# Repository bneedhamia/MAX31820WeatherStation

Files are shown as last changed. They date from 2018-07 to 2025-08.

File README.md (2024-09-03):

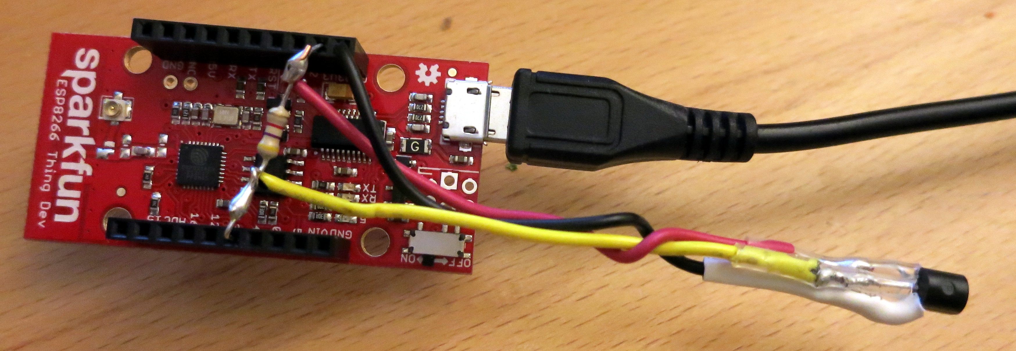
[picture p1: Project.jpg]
The Project so far

# MAX31820WeatherStation
An Arduino Sketch for a Sparkfun ESP8266 Thing Dev board, using a MAX31820 temperature sensor to sense and report the current ambient temperature to the Weather Underground via WiFi.

The state of the project: My weather station is installed on my garage wall, in the shade, and is sending the temperature to Weather Underground every 5 minutes. See Diary.odt for details.

The Arduino Sketch requires a Sparkfun ESP8266 Thing Dev board, a MAX31820 temperature sensor, a 4.7K Ohm pull-up resistor and a few wires. Details are in BillOfMaterials.ods. Total cost: about $28 USD.

I've posted a How-To in my BluePaperTech.com post [Build a Minimal Weather Underground Station](https://bluepapertech.com/electronics/build-a-minimal-weather-underground-station/).

## Files
* BillOfMaterials.ods = the parts list.
* box.stl = the 3D printing file for the box that holds the parts. Print in PLA, with no support, raft, or brim.
* boxLid.stl = the 3D printing file for the box's lid. Print in PLA, with no support, raft, or brim.
* Diary.odt = my journal/diary of the project, with design and assembly details.
* LICENSE = the project GPL2 license file.
* MAX31820WeatherStation.ino = the ESP8266 Arduino Sketch.
* MAX31820WeatherStation.FCStd = the FreeCAD design file for the box.
* MAX31820WeatherStation.fzz = the Fritzing (circuit wiring) diagram. See [Fritzing.org](http://fritzing.org)
* Project.jpg = a photo of the project so far.
* README.md = this file.

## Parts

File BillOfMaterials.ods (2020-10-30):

Bill Of Materials for MAX31820 Weather Underground station |  |  |  | All values are in US Dollars
Count | Name | Supplier | Part Number | Cost each | Total | Url | Notes
1 | SparkFun ESP8266 Thing - Dev Board | Sparkfun | WRL-13711 | $15.95 | $15.95 | https://www.sparkfun.com/products/13711
2 | Arduino Stackable Header - 10 Pin | Sparkfun | PRT-11376 | $0.50 | $1.00 | https://www.sparkfun.com/products/11376 | To plug wires into the ESP8266 Thing Dev board
1 | Wall Adapter Power Supply - 5.1V DC 2.5A (USB Micro-B) | Sparkfun | TOL-13831 | $7.95 | $7.95 | https://www.sparkfun.com/products/13831 | This supply powers the ESP8266
1 | One-Wire Ambient Temperature Sensor - MAX31820 | Sparkfun | SEN-14049 | $1.95 | $1.95 |  | Available for a little less at Digikey: https://www.digikey.com/product-detail/en/maxim-integrated/MAX31820MCR/MAX31820MCR-ND/4271348
10 | Resistor 4.7K OHM 1/4W 5% AXIAL | Digikey | 4.7KQBK-ND | $0.06 | $0.60 | https://www.digikey.com/products/en?keywords=4.7KQBK-ND | We need only 1, but they're useful enough to buy at least 10
1 | 3D Printed box with lid | -custom- |  |  |  | MAX31820WeatherStation.FCStd | Custom part. STL files and the Design file are in GitHub
 | TODO heat shrink tubing |  |  |  | $0.00
Total (Parts) |  |  |  |  | $27.45
Tools and Miscellaneous materials
1 | Heaterizer XL-3000 Heat Gun | Sparkfun | TOL-10326 | $13.95 | $13.95 |  | So much better and safer than trying to use matches or cigarette lighters to shrink the tubing.
1 | Hookup wire, solid, 22Awg, black | Sparkfun | PRT-08022 | $2.50 | $2.50 | https://www.sparkfun.com/products/8022 | Ground wires
1 | Hookup wire, solid, 22Awg, red | Sparkfun | PRT-08023 | $2.50 | $2.50 | https://www.sparkfun.com/products/8023 | Power wires
1 | Hookup wire, solid, 22Awg, yellow | Sparkfun | PRT-08024 | $2.50 | $2.50 | https://www.sparkfun.com/products/8024 | Arduino signal wires
Total (Wire and Tools) |  |  |  |  | $21.45

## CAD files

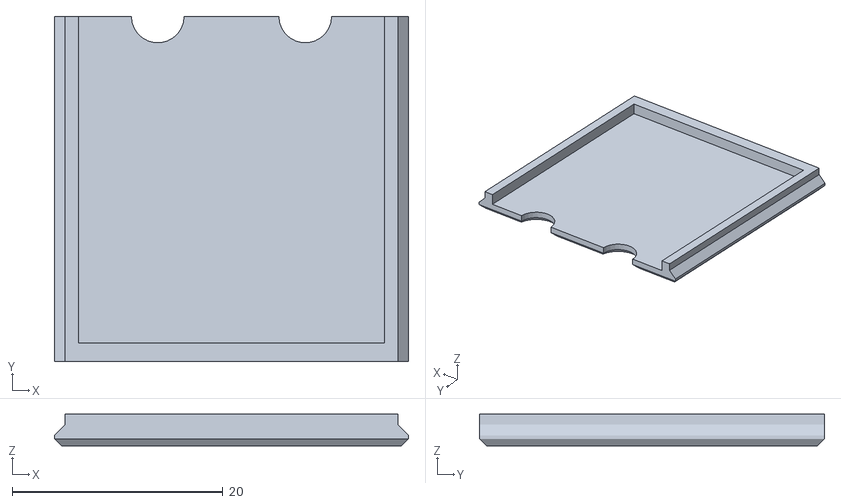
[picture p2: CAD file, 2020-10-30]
boxLid.stl
33.6 x 32.8 x 3.00

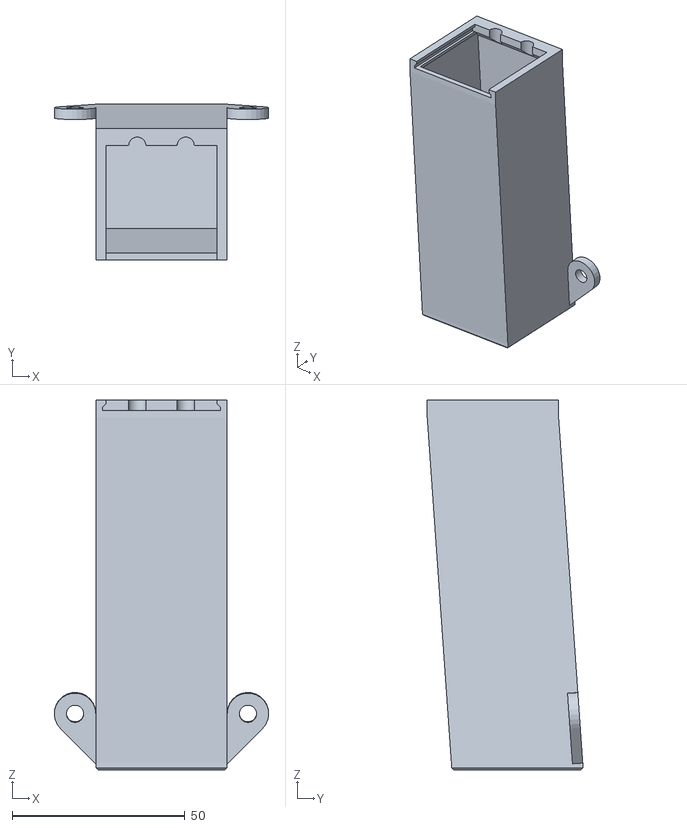
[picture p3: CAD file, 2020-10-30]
box.stl
62.0 x 45.0 x 107.0

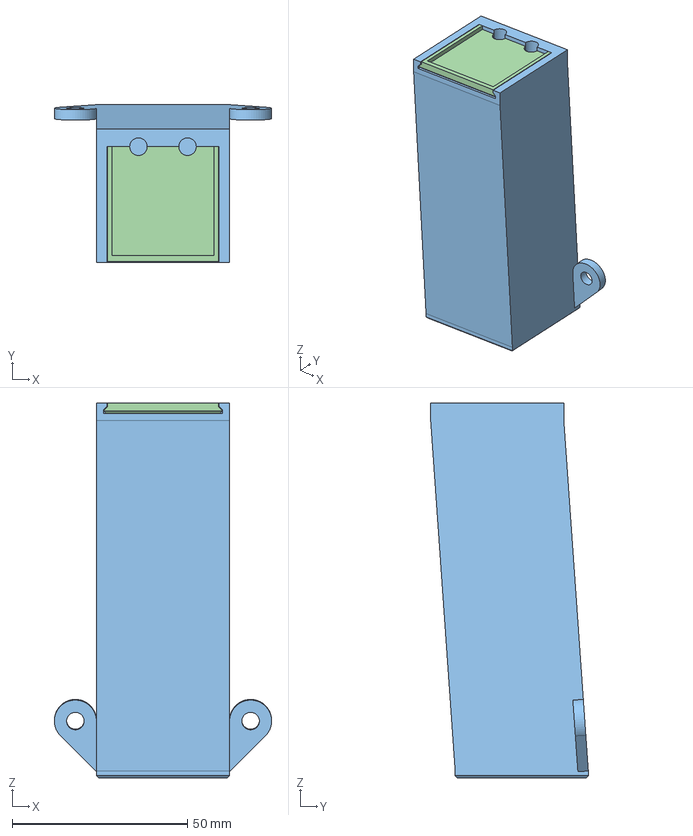
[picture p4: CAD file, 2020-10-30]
MAX31820WeatherStation.FCStd
62.0 x 45.0 x 107.0 mm
boxLid
RefinedBoxForPrinting
RefinedBoxLidForPrinting

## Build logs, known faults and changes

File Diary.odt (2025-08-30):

# Diary for the ESP8266 / MAX31820 Weather Underground Station

This project is a minimal, temperature-only weather station that reports to the Weather Underground, https://www.wunderground.com/ , via WiFi.

It uses a Sparkfun ESP8266 Thing Dev board as the Arduino, and one Max31820 Temperature Sensor to read the ambient temperature. The project is housed in a 3D printed box that has holes at the bottom for the USB power and the temperature sensor.

## 3D Printing and Assembly Instructions

1. I prefer PLA.
2. Print box.stl and boxLid.stl. Print without support, raft, or brim.
3. The lid may be a little tight the first few times you slide it in. It will loosen with wear.

## How to Register your Weather Station

1. Create a free account on Weather Underground, https://www.wunderground.com/
2. Log in to Weather Underground
3. Select, under My Profile, My Weather Stations
4. On the resulting screen, select the Register with WU tab
5. Follow the instructions to register your station, selecting "other" for Station Hardware.
6. Write down the resulting Station ID and Station Key. You will load these into the ESP8266 EEPROM so that the Arduino code doesn't have any private information in it. See instructions in the Arduino code (.ino) file for how to load the WiFi credentials and Station credentials into the ESP8266 EEPROM.
7. After a few minutes, power up your new weather station. It should upload the temperature every 10 minutes.

## Design Notes

- Weather Underground takes temperature in degrees Fahrenheit. The code converts from degrees Celsius (the MAX31820 native form) to degrees Fahrenheit for upload.
- My box will be put in a very damp environment (outside, under a balcony).
- The box holds an ESP8266 Thing Dev board and MAX31820 temperature sensor.
- It is powered by wall-powered USB, plugged into a nearby all-weather socket. My power supply is sheltered from the rain, so it should work fine. It will be interesting to see how it fares this winter. Update: it worked without problems.
- I created a slight slope to the top and bottom of the box by doing a Sweep operation. The slight slope should help keep water from pooling on the top of the box.
- The holes in the bottom lid of the box will pass the USB wire and the wires for the MAX31820.
- The temperature sensor is outside the box and below the ESP8266, to minimize the effect of the heat generated by the ESP8266.
- The ESP8266 board is 27mm wide. I added 2 mm clearance, so the box interior is 29 mm wide. The length from tip of pins to good clearance above the headers = about 29 mm, so I made the box square.
- From the tip of the ESP8266 board to the flexible part of the USB cable is 100 mm, so I made the box about 100 mm tall.
- The ESP8266 spec claims an operating temperature range of -40°~125° C, so we shouldn't have any trouble with low or high ambient temperatures here.

## Soldering the circuit

1. Solder the headers to the ESP8266.
2. Trim and bend the ends of the 4.7K Ohm resistor so it just fits with one end plugged into ESP8266 3.3V pin and the other into the data pin (labeled "4" on the ESP8266).
3. Cut 3 long (100 mm) pieces of hookup wire: Red for power, Yellow for data, and Black for ground. Solder them to the appropriate pins of the MAX31820. See the data sheet or my project photo for the pinout of the MAX31820. https://cdn.sparkfun.com/datasheets/Sensors/Temp/MAX31820.pdf
4. Cut 3 short pieces of heat shrink tubing. Slide one over each of the wires, to cover the soldered parts. Use a heat gun to shrink the tubing.
5. Solder the yellow data wire to the data (pin 4) side of the resistor.
6. Solder the red power wire to the power (3.3V) side of the resistor.
7. Cut the black wire to length and plug it into the GND pin on the ESP8266.

## Diary

August 30, 2025 – Extended the temperature wait time to fix an obscure 1 ms bug. Checked in the project using SSH.

August 29, 2025 – I think I have the SSH checkout/checkin figured out. Had to re-checkout the repository and fold in my changes because the old checkout wasn't with SSH.

February 12, 2025 – Put the new Weather Underground Certificate's fingerprint in the code.
Still haven't done the SSH work for Github.

September 3, 2024 – Updated the new Weather Underground Certificate's fingerprint in the code.
Unfortunately for me Github has changed the authentication method in the past few years and the instructions for using SSH with Github are tedious and full of options. I successfully changed the local repository's URL to SSH (see git remote -v), but the steps past that point are a mess.

October 23, 2021 – The station stopped working in July. Today I looked into it and found the Weather Underground site Certificate had been updated in July. Incorporated the new Certificate's fingerprint into the code and ran it; it uploaded just fine.

October 29 – the redesigned FreeCAD file prints and works great. I tightened the lid clearance so it won't fall out so easily.

October 27, 2020 – Autodesk changed the License terms for Fusion 360, so I'm switching back to FreeCAD, which is open source. I'm redesigning the weather station box from scratch to hopefully make a simpler design.

December 7 – Printed the Weather Station box. It works fine. Replaced the FreeCAD design file with a Fusion 360 design file; updated the .stl files.

December 6 - Finished the first draft of the 3D printed Weather Station box in Fusion 360. It's ready to print.

December 5 – Corrected the current time (millis()) to be unsigned long to match the return value from millis() and to correct some time rollover problems. It seems the code was correct; all I had to do was correct the declaration of nowMs.
Did some simple addition of an offset to the millis() result to test time rollover behavior of the time between Posts code. It succeeded.
Started working on the fix for the station not working if the WiFi Access Point is not available at ESP8266 powerup. Ran the HTTPSRequest Sketch (see notes below), testing the case of the AP not being up at startup (turning on after 5 minutes) – the ESP8266 library worked fine. Added a State to the state machine that's for Waiting For Access Point. Tried it out: it successfully handled powering up followed by the Access Point powering up a minute later.
Wrote a simple UrlEncoder and a unit test for it. The output is:

Output should be URL Encoded 0x01 through 0xff

%01%02%03%04%05%06%07%08%09%0A%0B%0C%0D%0E%0F%00%01%02%03%04%05%06%07%08%09%0A%0B%0C%0D%0E%0F%00%01%02%03%04%05%06%07%08%09%0A%0B%0C%0D%0E%0F...

So it looks like the upper digit isn't coming out correctly. It was a simple typo of >>8 instead of >>4. Fixed that and it ran fine.
Tested the normal running of the Sketch; the upload failed with "Unauthorized". So something's wrong with the urlencodedcat() use. Added a debug print of the Post content: the station ID and password look like they weren't null terminated: they contain piles of garbage characters. Read the function and found I'd forgotten to null terminate the output. Fixed that and the upload worked.
Started recreating the station 3D printed box in Fusion 360. The basic box and nail loops went together quickly. Took several tries at the slot for the case's bottom; I need to do one more try from scratch.

December 4, 2019 – Ran the weather station in my office. Changed the EEPROM to talk to the local SSID rather than the garage SSID. The sketch successfully connects to the local SSID, then says "Failed to connect to weatherstation.wunderground.com port 443". This happens before it even sends the SSL fingerprint. Perhaps the protocol has changed.
Found the URL of the protocol no longer works (404). Searched in vain for the Weather Underground Personal Weather Station protocol specification on the Weather Underground site.
Tried manually accessing the station update url of https://weatherstation.wunderground.com/weatherstation/updateweatherstation.php, and received a "bad request" response. That's good, that I didn't get a Not Found or other error.
Found a likely protocol description at The Weather Channel: https://feedback.weather.com/customer/en/portal/articles/2924682-pws-upload-protocol?b_id=17298, last updated June 2019. The protocol documented there seems unchanged.
Put the new update site in the code and tried it. Same error. Tried HTTP instead of HTTPS. Tried connecting to google.com via SSL. Same error, which suggests the problem is not the protocol, but is something to do with the network stack on the ESP8266.
Started reading the ESP8266 WiFi documentation, and found the WiFiClientSecure constructor is active, and should (likely) be constructed during setup() rather than at global variable initialization time before setup() is called. Changed doHttpsPost() to construct client each time it's called. No change.
Decided I need to back up and get a simple web client working again. Successfully ran the ESP8266 BasicHTTPSClient.ino example, so that shows the board works, but that code is very different than what this Sketch uses.
Once I corrected the fingerprint, I successfully ran https://github.com/esp8266/Arduino/blob/master/libraries/ESP8266WiFi/examples/HTTPSRequest/HTTPSRequest.ino, which uses the same API as this Sketch does/did. The big difference is that the working code uses client.fingerprint() to set the SSL fingerprint to use, while the non-working code uses the – very suspect – client.verify(fingerprint, host).
Updated the fingerprint setting code, corrected the fingerprint for the upload site – which was not the same as the one for the main wunderground.com site – and the Sketch successfully uploaded the temperature!
Implemented corrections to a few easy issues listed in this project's github repository.

December 1, 2019 – I took the station down sometime in the past year. I believe I did it because the station wasn't uploading to Weather Underground at all.
Read through the code, creating a GitHub Issue for each change that should be made.
Found that the SSL fingerprint for Weather Underground's site certificate is out of date; the corresponding SSL Certificate expired in September.

July 27 – Changed the upload interval from 10 minutes to 5 minutes, so Weather Underground won't mark a running station as down. Moved the weather station from the house balcony (which is typically 4 degrees Fahrenheit higher than the ambient air) to a garage wall that's in the shade. Found I forgot to reprogram the EEPROM to have it connect to the garage wifi hotspot. I also bent the sensor so it's a little further from the wall. We'll see if these changes improve the accuracy of the readings.

July 16, 2018 – Used two nails to hang the station on the outside wall of our balcony, reasonably sheltered from the sun. It's uploading just fine, and reads about 2 degrees F higher than a free-standing thermometer on the balcony.

July 15, 2017 – Built the hardware. Did a couple false starts because I'd forgotten why I was going to use a MAX31820 rather than a DHT22: the DHT22 is a 5.5V part and the ESP8266 Thing Dev is a 3.3V part. Also had forgotten that the 1-wire bus needs an external pullup resistor, so I need to solder something up rather than just using hookup wires with connectors on the ends.
Also found I seem to be out of MAX31280 parts. Need to order more. Stole one from my well depth sensor project.
I soldered the whole thing together: soldering the wires for power and data to either side of the 4.7K ohm pull-up resistor, soldered and heat-shrink-tubing covered the power, data, and ground hookup wires to the 3 pins of the temperature sensor.
Wrote the software: I modified my unfinished Well depth sensing Arduino Sketch, because that sketch reads from a set of MAX31820's and posts the results. Managed to run the sketch to print the 1-wire address of the temperature sensor I've soldered together (so Good News: I didn't break or overheat the sensor when soldering it.
Started putting together all the files for a github repository.

February 2 – Added lobes for nails/screws to fasten the box to the wall. Thought about, and initially discarded, the idea of sloping the top (bottom) so rain doesn't collect on the top of the box. If I redo the box, I'll do that plus I'll invert it so the model is right-side up for use (upside-down for printing).

Tried to print, but found after 45 minutes that it seems Cura decided that the box needed to be filled completely. Examining the bad file, I found doing a "Check Geometry" on the box model showed a fusion problem, and doing a Layers view in Cura also showed the problem of filling the entire box – so if I'd checked Geometry or looked at layers (always check layers view), I would have seen the problem without wasting plastic.

Redesigned the box from scratch, making it an angled thing to keep the rain out, and designing it upright, with the understanding that I print it all upside-down.

December 24 – With the snow and iffy weather, an outdoor thermometer sounds useful again.

Increased the horizontal clearance of the door from 0.5mm total (0.25mm each side) to 0.75 mm total (0.375mm per side).

December 2, 2017 – Considering different ways to enclose the ESP8266, to keep it dry enough. Thinking about a 3D printed, tube-like box with a slide-snap bottom. Did a quick sketch and printed a short version of the box as a clearance test. Found a couple things to fix.

Did a second iteration. Started a full-sized print. Still need to add something to fasten it to the side of the house.

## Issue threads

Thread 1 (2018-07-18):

10 minute updates make Weather Underground report that the station is down

bneedhamia, 2018-07-18:
The current Sketch reports the temperature every 10 minutes. I once saw Weather Underground report that my Personal Weather Station wasn't reporting, and that the latest report was from just a few minutes ago.

I've searched, but haven't (yet) found any Weather Underground specification of how infrequently a station can report and still be considered up.

I have found reports elsewhere that make me think that reducing the time between reports to 5 or 4 minutes would be a good idea. Some commercial weather stations seem to report once per minute or more frequently, to report the changing wind direction or swiftly-changing temperature.

Doing an informal survey of Weather Underground Personal Weather Station update times (as shown in WU's tabular weather data for a station) shows most of them are reporting about once per 5 minutes.

I recommend changing the reporting interval from 10 minutes to 5 minutes.

bneedhamia, 2018-07-27:
Weather Underground data table shows this station is now reporting every 5 minutes.

Closed 2018-07-27.

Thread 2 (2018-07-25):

Won't reconnect if wifi is down on powerup

bneedhamia, 2018-07-25:
The Sketch attempts to connect to WiFi only in Setup(), and goes to an error state if it can't connect. If the WiFi hotspot is down when the station is powered up, the station won't report until the station power is manually reset.

In short, the station won't recover properly from a power outage, because when power is restored, the WiFi isn't up yet when the station powers up.

The fix: expand the state machine to include WiFi connection-related states.

bneedhamia, 2019-12-05:
I tested the ESP8266 HTTPSRequest Sketch (https://github.com/esp8266/Arduino/blob/master/libraries/ESP8266WiFi/examples/HTTPSRequest/HTTPSRequest.ino), which simply waits forever for the WiFi Access Point to connect. Found I can start that Sketch with the AP off, turn the AP on 10 minutes later, and the Sketch will connect to it and run.
So I want to add a state to the loop() State Machine that indicates the Sketch is waiting for the ESP8266 to connect to the Access Point. I'll also make the EEPROM timeout parameter unused, but will leave it in in case a later version needs it.

bneedhamia, 2019-12-05:
Successfully tested the waiting for the WiFi AP to power up, and the new EEPROM layout that doesn't have a WiFi AP timeout.

bneedhamia, 2020-01-07:
We had a brief power outage, where the internet came up several minutes after the power came on. The station successfully resumed updating when the net came back.

Closed 2019-12-05.

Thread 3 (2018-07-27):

Serial Output of temperature should show units (C)

bneedhamia, 2018-07-27:
A very minor nit: the Serial printout of temperature doesn't say that it's C rather than F. It's pretty easy to guess that on a hot day a temperature of 28 isn't in Fahrenheit, but it's nice to be sure.

Add a "C" after the serial printout of the temperature in C.

bneedhamia, 2019-12-05:
Verified that it prints "C" after the debug temperature output.

Closed 2019-12-05.

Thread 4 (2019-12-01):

Won't upload to Weather Underground?

bneedhamia, 2019-12-01:
I seem to recall I took the station down because it no longer uploaded to Weather Underground.

TO DO: Check whether or not it uploads, and if not, find what the problem is.

bneedhamia, 2019-12-01:
One cause: the SSL Certificate I used a few years ago expired in September of 2019. So I need to re-read the Weather Underground's SSL Certificate, generate its fingerprint (as described in the .ino file) and manually update sslFingerprint[].

bneedhamia, 2019-12-05:
The problem seems to be the use of the ESP8266 WiFi stack rather than any change in the protocol. Even trying to connect to google.com on port 443 fails.

bneedhamia, 2019-12-05:
I watched it successfully upload my office temperature to Weather Underground 4 times.

Closed 2019-12-05.

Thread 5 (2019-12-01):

Change httpAgent to MAX31820WeatherStation

bneedhamia, 2019-12-01:
The current httpAgent name of the station, ESP8266HttpsClient, is too generic. Change httpAgent to the name of this repository, so that if there's a problem and someone searches the web for MAX31820WeatherStation, they'll find this repository.

bneedhamia, 2019-12-05:
Seems to work with the new HTTPS client name.

Closed 2019-12-05.

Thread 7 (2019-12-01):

In loop(), change nowMs to unsigned long, and correct related code

bneedhamia, 2019-12-01:
In loop() the current time, nowMs, is currently a signed long, but millis() returns an unsigned long. This means that nowMs will change from a positive to a negative number as the program runs. I believe this currently doesn't cause an error, but it's misleading and could easily cause future code changes to be incorrect.

bneedhamia, 2019-12-05:
Tested the time rollover for Post timing; it seemed to work.

Closed 2019-12-05.

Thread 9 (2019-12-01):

Add Fusion 360 design file for the case

bneedhamia, 2019-12-01:
I was using FreeCAD when I designed the case for the station. Since then I've switched to Fusion 360, which seems far more popular than FreeCAD in the 3D printing community.

Create a new case design in Fusion 360 and create new .STL files. Remove the old case design.

bneedhamia, 2019-12-08:
Tried out the new, Fusion 360 based, box for the weather station. It's almost identical to the FreeCAD version.

Closed 2019-12-08.

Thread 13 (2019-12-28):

Add 1 millisecond to temperature reading delay

bneedhamia, 2019-12-28:
I believe that some of the time the temperature is read before it's ready.

The MAX31820 Datasheet, https://cdn.sparkfun.com/datasheets/Sensors/Temp/MAX31820.pdf, specifies the maximum temperature conversion time for a 12-bit reading is 750ms. The Dallas Temperature library, https://github.com/milesburton/Arduino-Temperature-Control-Library/blob/master/DallasTemperature.cpp, returns, for the time required for a 12-bit conversion, 750ms. Meanwhile this Sketch code tests whether it's time to read the converted temperature via an if statement that says whether it's not yet time: (long) (nowMs - stateBegunMs) < wireDevices.millisToWaitForConversion(MAX31820_RESOLUTION_BITS)

The bug is that the Sketch doesn't allow for millis() rounding/truncation of the current time to milliseconds. For example, two subsequent calls to millis() could return results that differ by 1ms, even though the calls happened much less than 1ms apart. So any test of time that doesn't allow for this effect could say that things are ready as much as 1ms earlier than they really are.

Solution:  change the if statement in STATE_WAITING_FOR_TEMPERATURES to wait for the conversion time plus 1ms, to be safe.

bneedhamia, 2025-08-30:
Added the 1ms delay.

Closed 2025-08-30.

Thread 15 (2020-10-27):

Remove dependencies on the proprietary CAD program, Fusion 360

bneedhamia, 2020-10-27:
Fusion 360 is a proprietary application. Meanwhile, FreeCAD is FOSS (Free and Open Source Software).

Replace the 3D printing design file and output files with FreeCAD counterparts.

bneedhamia, 2020-10-30:
Replaced the Fusion 360 file with a new FreeCAD file.

Closed 2020-10-30.

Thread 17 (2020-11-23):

Upload is failing again - likely the Wunderground site certificate fingerprint needs to be updated.

bneedhamia, 2020-11-23:
My station stopped uploading months ago. I suspect the site certificate has been updated.

bneedhamia, 2020-11-23:
Recompiling in my office with new WiFi credentials and the same old code seems to work fine. Now I suspect the problem was with a WiFi hotspot that needed to be reset. Double-checked the site certificate fingerprint hasn't changed.

Closed 2020-11-23.

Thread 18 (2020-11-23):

Wunderground test URL in the comments is incorrect

bneedhamia, 2020-11-23:
"Browse to an https: page on the desired server.
       E.g., https://weatherstation.winderground.com" has a typo; that should be wunderground instead of winderground.
This typo led me to believe that the site or protocol had changed, because the browser reported the name wasn't found.

bneedhamia, 2020-11-23:
Corrected the typo.

Closed 2020-11-23.

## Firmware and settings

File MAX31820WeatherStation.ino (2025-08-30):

/*
   Arduino Sketch for a Sparkfun ESP8266 Thing Dev board
   to read the ambient temperature from a MAX31820 chip
   and send that temperature to Weather Underground.

   NOTE: You will need to update sensorAddress{}
   and likely update sslFingerprint[]. See the comments by those variables.
   You will also need to program the EEPROM. See "The EEPROM layout" below.

   Copyright (c) 2018, 2019 Bradford Needham
   { @bneedhamia , https://www.needhamia.com }

   Licensed under GPL V2
   a copy of which should have been supplied with this file.
*/
//345678901234567890123456789312345678941234567895123456789612345678971234567898

/*
   Flags to change the program behavior:
   
   PRINT_1_WIRE_ADDRESS = uncomment this line to only
     print the temperature sensor's 1-wire address,
     so you can copy it into the sensorAddress[] initializer.
     Comment this line out for normal Sketch behavior.

   TEST_URL_ENCODING = uncomment this line to only
     test the urlencodedcat() function.
     Used only during development of urlencodedcat().
     Comment this line out for normal Sketch behavior.
*/
//#define PRINT_1_WIRE_ADDRESS true
//#define TEST_URL_ENCODING true

/*
    NOTE: because the ESP8266 WiFi operates in the background,
     setup() and loop() must not take a long time.
     In particular, never call any delay() greater than
     a few hundred milliseconds.
 */
#include <ESP8266WiFi.h> // Defines WiFi, the WiFi controller object
#include <WiFiClientSecure.h>
#include <EEPROM.h>   // NOTE: ESP8266 EEPROM library differs from Arduino's.
#include <OneWire.h>  // https://github.com/PaulStoffregen/OneWire
#include <DallasTemperature.h> // https://github.com/milesburton/Arduino-Temperature-Control-Library

/*
   Web Site specific constants.
     host = the hostname of the server to connect to.
     port = the HTTPS port to connect to (443 is the default).
     sslFingerprint = the SHA1 fingerprint of the SSL Certificate
       of the web site we will be connecting to.
     httpProtocol = the protocol to use. Some sites prefer HTTP/1.1.
       This Sketch uses HTTP/1.0 to avoid getting a response that is
       Transfer-encoding: chunked
       which is hard to parse.
     url = the url, less https:// and the server name.
     httpAgent = a string to identify our client software.
       This Sketch uses the name of the Github Repository of this project.
       Replace this with whatever you like (no spaces).

     To Find the Fingerprint of a site:
     - Browse to an https: page on the desired server.
       E.g., https://weatherstation.wunderground.com
       (you may get a 404 error; that's ok).
     - Copy the certificate from that page. There are instructions
       on how to do this in various browsers. Search for
       "read the certificate from a website in Chrome" (without quotes)
       or whatever web client you prefer.
     - Save the certificate in Base-64 encoded X.509
     - In git bash (or in a linux terminal window), type
       openssl x509 -noout -fingerprint -sha1 -inform pem -in certificate-file.cer
       Where "certificate-file.cer" is the filename of the certificate you saved.
     - in the response, copy the colon-separated set of numbers.
     - paste them in the sslFingerprint initializer below.
     - replace each ":" character in sslFingerprint with a space.
     Note: when the site's certificate expires and is updated, you will need to
     update the code here with the new SSL certificate signature.

     The Weather Underground Personal Weather Station upload protocol
     is specified at https://support.weather.com/s/article/PWS-Upload-Protocol
*/
const char *host = "weatherstation.wunderground.com";
const int port = 443;
const char *sslFingerprint
  = "F1 C6 8A 62 8C 8B 1D 87 3A 29 10 B8 09 3F C1 96 79 A7 2E 35";
  // Certificate expires 12 Mar 2026, but it may be replaced earlier.
const char *httpProtocol = "HTTP/1.0";
const char *url = "/weatherstation/updateweatherstation.php";
const char *httpAgent = "MAX31820WeatherStation";

/*
   Hardware information:

   PIN_LED_L = LOW to light the on-board LED.
     The _L suffix indicates that the pin is Active-Low.
     Active-Low because that's how the ESP8266 Thing Dev board
     on-board LED is wired.
     When the LED is steady-on, we're waiting to connect to the WiFi.
     When the LED is blinking, we've encountered a non-recoverable error.
     When the LED is off, things are working correctly.
     
   PIN_ONE_WIRE = the 1-Wire bus data line for the temperature sensor.
   
   Note about the ESP8266 Thing Dev board I/O pins: several pins are unsuitable
   to be a 1-wire bus:
     0 is connected to an on-board 10K ohm pull-up resistor.
     2 is connected to an on-board 10K ohm pull-up resistor.
     5 is connected to an on-board LED and 220 ohm resistor to Vcc.
     15 is connected to an on-board 10K pull-down resistor.
     16 is not (currently) supported by the OneWire library, because
       that pin requires special treatment in the low-level I/O code.
*/
const int PIN_LED_L = 5;
const int PIN_ONE_WIRE = 4;

/*
   Time (milliseconds) per attempt to read and report the temperatures.
   Set this to about 5 minutes (1000L * 60L * 5L) for normal operation,
   so you don't overwhelm the server.
*/
const long MS_PER_TEMPERATURE_REQUEST = 1000L * 60L * 5L;

/*
   The resolution (number of bits) to set the temperature sensor to.
   12 is the maximum; 9 is the minimum.
   Higher resolution takes longer (see the Max31820 datasheet for details)
   but is more precise.
*/
const uint8_t MAX31820_RESOLUTION_BITS = 12;

/*
   The EEPROM layout, starting at START_ADDRESS, is:
   String[EEPROM_WIFI_SSID_INDEX] = WiFi SSID. A null-terminated string
   String[EEPROM_WIFI_PASS_INDEX] = WiFi Password. A null-terminated string
   String[EEPROM_STATION_ID_INDEX] =
     the HTTPS POST Weather Underground station ID parameter to send.
   String[EEPROM_STATION_KEY_INDEX] =
     the HTTPS POST Weather Underground station key parameter to send.
   EEPROM_END_MARK

   To create a Station ID and Key for your particular weather station,
   visit https://www.wunderground.com/member/devices/new

   To write these values, use the Sketch write_eeprom_strings.
   See https://github.com/bneedhamia/write_eeprom_strings
   Modify that Sketch, replacing the initialization of STRING_NAME[] with
   the following lines:

  const char *STRING_NAME[] = {
  "SSID",
  "Password",
  "stationId",
  "stationKey",
  0
  };

*/
const int START_ADDRESS = 0;      // The first EEPROM address to read from.
const byte EEPROM_END_MARK = 255; // marks the end of the data we wrote to EEPROM
const int EEPROM_MAX_STRING_LENGTH = 120; // max string length in EEPROM
const int EEPROM_WIFI_SSID_INDEX = 0;
const int EEPROM_WIFI_PASS_INDEX = 1;
const int EEPROM_STATION_ID_INDEX = 2;
const int EEPROM_STATION_KEY_INDEX = 3;

/*
   The states of the state machine that loop() runs.

   state = the current state of the machine. A STATE_* value.
   stateBegunMs = if needed, the time (millis()) we entered this state.

   STATE_ERROR = an unrecoverable error has occurred. We stop.
   STATE_WAITING_FOR_WIFI = we're waiting for the WiFi to connect
     with the Access Point.
   STATE_WAITING_FOR_TEMPERATURES = we've issued a command to the sensors
     to read the temperature, and are waiting for the time to read
     their responses.
     For example, a 12-bit temperature read requires 750ms.
     stateBegunMs = time (millis()) we entered this state.
   STATE_WAITING_FOR_NEXT_READ = we're waiting to request temperature again.
*/

const uint8_t STATE_ERROR = 0;
const uint8_t STATE_WAITING_FOR_WIFI = 1;
const uint8_t STATE_WAITING_FOR_TEMPERATURES = 2;
const uint8_t STATE_WAITING_FOR_NEXT_READ = 3;
uint8_t state;
unsigned long stateBegunMs = 0L;

/*
   wire = The 1-Wire (thermometer) interface manager.
   wireDevices = the manager for the1Wire devices (thermometers).
 */
OneWire wire(PIN_ONE_WIRE);
DallasTemperature wireDevices(&wire);

/*
   WiFi access point parameters, read from EEPROM.

   wifiSsid = SSID of the local WiFi Access Point to connect to.
   wifiPassword = Password of the Access Point.
*/
char *wifiSsid;
char *wifiPassword;

/*
   HTTPS POST private parameters, read from EEPROM.
   stationId = the POST 'ID' parameter.
   stationKey = the POST 'PASSWORD' parameter.
*/
char *stationId;
char *stationKey;

/*
   sensorAddress = the 1-wire address of the temperature sensor on the 1-wire bus.
   Update this array for your unique temperature sensor.

   Create this initializer by:
   1) Wiring up the temperature sensor to the ESP8266, as described in Diary.odt
   2) Uncommenting PRINT_1_WIRE_ADDRESS (above)
   3) Running the Sketch, and copying and pasting the output here.
   4) Commenting out PRINT_1_WIRE_ADDRESS (above)
   5) Running the Sketch as normal.
*/
DeviceAddress sensorAddress = {0x28, 0xAB, 0xA8, 0xA8, 0x7, 0x0, 0x0, 0x78};

/*
   The result of measurement:

   stationTemperatureC = the temperature (degrees Celsius) read from the sensor,
    or <= DEVICE_DISCONNECTED_C if the sensor failed.
*/
float stationTemperatureC;

// Called once automatically on ESP8266 Reset.
void setup() {
  Serial.begin(9600);
  delay(100); // give the Serial port time to power up.
  Serial.println(F("Reset."));

#if defined(TEST_URL_ENCODING)
  testUrlencodedcat();
  state = STATE_ERROR;
  return;
#endif // defined(TEST_URL_ENCODING)

  // Set up our pins.

  pinMode(PIN_LED_L, OUTPUT);
  digitalWrite(PIN_LED_L, HIGH); // ESP8266 Thing Dev LED is Active Low
  // PIN_ONE_WIRE is managed by the OneWire library.

  wireDevices.begin();  // searches the 1-wire bus for devices.

#if defined(PRINT_1_WIRE_ADDRESS)
  // Report the device addresses, in no particular order, and quit.
  print1WireAddresses();

  state = STATE_ERROR;
  return;
#endif

  // Read the wifi parameters from EEPROM, if they're there.
  wifiSsid = readEEPROMString(START_ADDRESS, EEPROM_WIFI_SSID_INDEX);
  wifiPassword = readEEPROMString(START_ADDRESS, EEPROM_WIFI_PASS_INDEX);
  if (wifiSsid == 0 || wifiPassword == 0) {
    Serial.println(F("EEPROM not initialized."));

    state = STATE_ERROR;
    return;
  }

  // Read our Weather Underground station credentials from EEPROM
  stationId = readEEPROMString(START_ADDRESS, EEPROM_STATION_ID_INDEX);
  stationKey = readEEPROMString(START_ADDRESS, EEPROM_STATION_KEY_INDEX);
  if (stationId == 0 || stationKey == 0) {
    Serial.println(F("EEPROM not initialized."));

    state = STATE_ERROR;
    return;
  }

  /*
     Set up the temperature sensor:
     Set the digital temperature resolution.
     Set the library to have requestTemperatures() return immediately
       rather than waiting the (too long for our WiFi) conversion time.
  */
  wireDevices.setResolution(MAX31820_RESOLUTION_BITS);
  wireDevices.setWaitForConversion(false);

  // Finally, do the one-time WiFi setup and request connection
  WiFi.mode(WIFI_STA);    // Station (Client), not soft AP or dual mode.
  WiFi.setAutoConnect(false); // don't connect until we call .begin()
  WiFi.setAutoReconnect(true); // if the connection drops, reconnect.

  Serial.print(F("Connecting to "));
  Serial.println(wifiSsid);
  WiFi.begin(wifiSsid, wifiPassword);

  state = STATE_WAITING_FOR_WIFI;
  stateBegunMs = millis();
}

// Called repeatedly, automatically.
void loop() {
  unsigned long nowMs; // The current time (millis())
  int wifiStatus;  // connection state of the WiFi.

  nowMs = millis();

  switch (state) {
    case STATE_ERROR:
      // Blink the led.
      if (nowMs % 1000 < 500) { // will be slightly long at millis() rollover.
        digitalWrite(PIN_LED_L, LOW);
      } else {
        digitalWrite(PIN_LED_L, HIGH);
      }
      break;

    case STATE_WAITING_FOR_WIFI:
      // Waiting for either WiFi connection or connection failure.
      
      wifiStatus = WiFi.status();
      if (wifiStatus == WL_CONNECT_FAILED) {
        // bad password. Fail.
        Serial.print(F("Password incorrect for "));
        Serial.println(wifiSsid);
        state = STATE_ERROR;
        stateBegunMs = millis();
        
      } else if (wifiStatus == WL_NO_SSID_AVAIL) {
        // Show we're waiting.
        digitalWrite(PIN_LED_L, LOW);

        // Continue to wait for the WiFi AP to become available.
        // This state is our house-power-fail recovery state.
        
      } else if (wifiStatus == WL_CONNECTED) {
        // We've connected to WiFi. Start reading temperatures.
        Serial.print(F("Connected, IP address: "));
        Serial.println(WiFi.localIP());

        // Indicate we're working fine.
        digitalWrite(PIN_LED_L, HIGH);

        // Ask the sensor to read its temperature.
        wireDevices.requestTemperatures();
        state = STATE_WAITING_FOR_TEMPERATURES;
        stateBegunMs = millis();
      }
      break;

    case STATE_WAITING_FOR_TEMPERATURES:
      if ((long) (nowMs - stateBegunMs)
          < wireDevices.millisToWaitForConversion(MAX31820_RESOLUTION_BITS) + 1) {
        return; // wait more.
      }

      // The temperature is ready. Read and print it.
      stationTemperatureC = wireDevices.getTempC(sensorAddress);

      if (stationTemperatureC <= DEVICE_DISCONNECTED_C) {
        Serial.print("NC");
      } else {
        Serial.print(stationTemperatureC, 2);
        Serial.print(" C");
      }
      Serial.println();

      // Report our data to the web server.
      if (doHttpsPost()) {
        digitalWrite(PIN_LED_L, HIGH); // success: turn off the LED.
      } else {
        digitalWrite(PIN_LED_L, LOW); // recoverable failure: turn on the LED.
      }

      // Wait until it's time to request the temperature again.
      state = STATE_WAITING_FOR_NEXT_READ;
      stateBegunMs = millis();

      break;

    case STATE_WAITING_FOR_NEXT_READ:
      if ((long) (nowMs - stateBegunMs) < MS_PER_TEMPERATURE_REQUEST) {
        return; // wait more.
      }

      // Ask the sensor to read its temperature.
      wireDevices.requestTemperatures();
      state = STATE_WAITING_FOR_TEMPERATURES;
      stateBegunMs = millis();
      break;

    default:
      Serial.print("unknown state: ");
      Serial.println(state);
      state = STATE_ERROR;
      break;
  }
}

/*
    Uploads the temperature - that's all our weather station knows.
    Uses:
      stationId, stationKey
      stationTemperatureC
      and the server information (host, post, etc.)

    Returns true if successful, false otherwise.
*/
boolean doHttpsPost() {
  char content[1024];  // Buffer for the content of the POST request.
  char *pContent;  // a pointer into content[]
  char ch;

  // client = manager of the HTTPS connection to the web site.
  WiFiClientSecure client;


  /*
     Build the content of the POST. That is, the parameters.
     UrlEncode the fields that can contain arbitrary text. 
   */

  strcpy(content, "");

  strcat(content, "ID=");
  urlencodedcat(content, stationId);

  strcat(content, "&");
  strcat(content, "PASSWORD=");
  urlencodedcat(content, stationKey);
  
  strcat(content, "&");
  strcat(content, "action=updateraw"); // says "I'm posting the weather"

  strcat(content, "&");
  strcat(content, "dateutc=now"); // says when the data was collected
  
  if (stationTemperatureC > DEVICE_DISCONNECTED_C) {
    // Convert the temperature from Celsius to Fahrenheit
    float temperatureF = stationTemperatureC * (9.0 / 5.0) + 32.0;
    
    strcat(content, "&");
    strcat(content, "tempf=");
    floatcat(content, temperatureF);
  } // else ignore the disconnected sensor.

  // Perform the Post

  client.setFingerprint(sslFingerprint);
  if (!client.connect(host, port)) {
    Serial.print("Failed to connect to ");
    Serial.print(host);
    Serial.print(" port ");
    Serial.println(port);
    Serial.print(" using SSL fingerprint ");
    Serial.print(sslFingerprint);
    Serial.println();
    return false;
  }
  Serial.print("Connected to ");
  Serial.println(host);

  client.print("POST ");
  client.print(url);
  client.print(" ");
  client.println(httpProtocol);

  client.print("Host: ");
  client.println(host);

  client.print("User-Agent: ");
  client.println(httpAgent);

  client.println("Connection: close");

  client.println("Content-Type: application/x-www-form-urlencoded");

  client.print("Content-Length: ");
  client.println(strlen(content));

  client.println();  // blank line indicates the end of the HTTP headers.

  // send the content: the POST parameters.
  client.print(content);

  Serial.println("Reading response:");
  while (client.connected()) {
    if (client.available()) {
      ch = client.read();
      Serial.print(ch);
    }
    delay(1); // to yield the processor for a moment.
  }

  Serial.println();
  Serial.println("connection closed.");

  client.stop();

  return true;
}

/*
   Append (concatenate) the given floating-point number
   as a string to the given buffer.

   buffer = a space to concatenate into. It must contain a null-terminated
    set of characters.
   f = the floating point number to convert into a set of characters.

*/
void floatcat(char *buffer, float f) {
  char *p;
  long l;

  p = buffer + strlen(buffer);

  // Convert the sign.
  if (f < 0.0) {
    *p++ = '-';
    f = -f;
  }

  // Convert the integer part.
  l = (long) f;
  f -= (float) l;
  itoa(l, p, 10);
  p += strlen(p);

  // Convert the first 2 digits of the fraction.
  *p++ = '.';
  f *= 100.0;
  itoa((long) f, p, 10);
}

/*
   Append (concatenate) the given string to the given buffer,
   UrlEncoding the string as it is appended.

   buffer = a space to concatenate into. It must contain a null-terminated
    set of characters, and be large enough to store the result.
   str = points to the null-terminated string to UrlEncode and append.

*/
void urlencodedcat(char *buffer, char *str) {
  char *pBuf; // points to the next empty space in buffer[]
  char *pIn;  // points to a character in str[]
  char ch;  // the current input character to UrlEncode.
  char hexDigit[] = "0123456789ABCDEF";

  pBuf = buffer + strlen(buffer);
  
  for (pIn = str; *pIn; ++pIn) {
    ch = *pIn;
    if (isAlphaNumeric(ch)) {
      // Alphabetic and numeric characters are passed as-is.
      *pBuf++ = ch;
      continue;
    }
    
    /*
       All other characters are encoded as a % followed by
       two hexidecimal characters. E.g., = is encoded as %3D.
       Reference: https://developer.mozilla.org/en-US/docs/Glossary/percent-encoding
     */

     *pBuf++ = '%';
     *pBuf++ = hexDigit[((int) ch >> 4) & 0xF];
     *pBuf++ = hexDigit[((int) ch) & 0xF];
  }

  *pBuf = (char) 0; // null terminate the output.
}

#if defined(TEST_URL_ENCODING)
/*
   A simple unit test of the Url Encoding function.
 */
void testUrlencodedcat() {
  static char input[255 + 1]; // 255 = 1..255, +1 for terminating null
  static char output[255 * 3 + 1]; // 256 * 3 for each encoded char, +1 for terminating null

  Serial.println(F("Output should be URL Encoded 0x01 through 0xff"));
  
  output[0] = (char) 0;
  char *pIn = input;
  for (int i = 1; i < 256; ++i) {
    *pIn++ = (char) i;
  }
  *pIn = (char) 0;

  urlencodedcat(output, input);

  Serial.println(output);
  
}
#endif // defined(TEST_URL_ENCODING)

/*
   Prints the 1-wire address of each device found on the 1-wire bus.
   The output is in a form that can be copied and pasted into an array
   initializer.

   Returns the number of devices on the bus if successful,
   0 if there is an error.
*/
uint8_t print1WireAddresses() {
  uint8_t numDevices;

  numDevices = wireDevices.getDeviceCount();
  Serial.print(numDevices);
  Serial.println(" temperature sensors responded:");

  DeviceAddress address;
  for (int i = 0; i < numDevices; ++i) {
    if (!wireDevices.getAddress(address, i)) {
      Serial.print("Sensor[");
      Serial.print(i);
      Serial.println("] was not found.");
      return 0;
    }
    Serial.print("  ");
    print1WireAddress(address);
    if (i < numDevices - 1) {
      Serial.print(",");
    }
    Serial.println();
  }

  return numDevices;
}

/*
   Prints a device address in a form that can be pasted into Arduino code
   as an initializer of a DeviceAddress variable.
*/
void print1WireAddress(DeviceAddress addr) {
  Serial.print("{");
  for (int i = 0; i < 8; ++i) {
    if (i != 0) {
      Serial.print(", ");
    }
    Serial.print("0x");
    Serial.print(addr[i], HEX);
  }
  Serial.print("}");
}

/********************************
   From https://github.com/bneedhamia/write_eeprom_strings example
*/
/*
   Reads a string from EEPROM.  Copy this code into your program that reads EEPROM.

   baseAddress = EEPROM address of the first byte in EEPROM to read from.
   stringNumber = index of the string to retrieve (string 0, string 1, etc.)

   Assumes EEPROM contains a list of null-terminated strings,
   terminated by EEPROM_END_MARK.

   Returns:
   A pointer to a dynamically-allocated string read from EEPROM,
   or null if no such string was found.
*/
char *readEEPROMString(int baseAddress, int stringNumber) {
  int start;   // EEPROM address of the first byte of the string to return.
  int length;  // length (bytes) of the string to return, less the terminating null.
  char ch;
  int nextAddress;  // next address to read from EEPROM.
  char *result;     // points to the dynamically-allocated result to return.
  int i;
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

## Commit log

2018-07-16 Tidied up a bit; Added a circuit diagram
    [BillOfMaterials.ods, MAX31820WeatherStation.fzz]
2018-07-27 #1 Changed upload interval to 5 minutes (from 10) so Weather Underground won't mark a running station as down.
    [MAX31820WeatherStation.ino]
2019-12-05 Corrected the URL of the Weather Underground protocol documentation
    [MAX31820WeatherStation.ino]
2019-12-05 #4 Corrected setting of SSL fingerprint; moved WiFiClient into the Post function.
    [MAX31820WeatherStation.ino]
2019-12-05 #3 Added units (Celsius) to the serial output of temperature
2019-12-05 #6 Removed obsolete comments about multiple temperature sensors; cleaned the comments
2019-12-05 #7 Corrected the type of variables that store millis() return value; checked the code that uses those variables.
    [MAX31820WeatherStation.ino]
2019-12-08 #9 Replaced the FreeCAD design file with a Fusion 360 design file.
    [BillOfMaterials.ods, MAX31820WeatherStation.f3d, ProjectBox.FCStd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]
2020-10-30 #15 Recreated the box design in FreeCAD, to eliminate dependencies on the proprietary Fusion 360.
    [BillOfMaterials.ods, MAX31820WeatherStation.FCStd, MAX31820WeatherStation.f3d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]
2020-11-23 #18 Corrected the Wunderground URL in the comments. Also added a note that the site certificate could be replaced before it expires.
    [MAX31820WeatherStation.ino]
2021-10-23 Updated the Weather Underground site Certificate Fingerprint
2023-08-07 updated the Weather Underground SSL Fingerprint
2025-08-29 Replaced WeatherUnderground SSL fingerprint for new site certificate
    [MAX31820WeatherStation.ino]
2025-08-30 #13 Added 1ms delay in reading temperature
2026-01-25 #21 Added comments that SSID is case-sensitive
2026-01-25 Updated the weather underground site fingerprint
